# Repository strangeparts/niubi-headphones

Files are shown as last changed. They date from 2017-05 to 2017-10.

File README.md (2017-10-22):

# niubi-headphones
Flexible circuit board design for adding a headphone jack to an iPhone 7

The design of this project is free for everyone. You have my full permission to make modification and improvement however you like.

Here is a picture of the board on the bottom flex cable.

I have used the internal circuit board from an official Apple headphone adapter.  The circuit connects this board to the lightning jack on the bottom flex connector.  When something is plugged into the lightning jack, the signal is switched from the headphone adapter to the lightning jack.  There is a 1 megaohm resistor that pulls the shield of the lightning connector to 3v.  This is shorted to ground when a connector is plugged into the headphone jack. This is how the switching chip senses that something was plugged in.  Whenever something is plugged or unplugged, one of the two timers fires, temporarily disabling the switching chip for 100ms (I think), which appears to be necessary for the phone to sense that something has been plugged in.

There are a couple limitations of this design:
- You cannot use the headphone jack while anything is plugged into the lightning jack.
- You need to move taptic engine and battery upward and shave the headphone jack, case, and screen to get enough room for the flex pcb, headphone adapter board, and flex pcb to fit.

## Contribute

If you decide to improve or manufacture this - I would love to hear from you.  You can contact me here: https://strangeparts.com/contact.

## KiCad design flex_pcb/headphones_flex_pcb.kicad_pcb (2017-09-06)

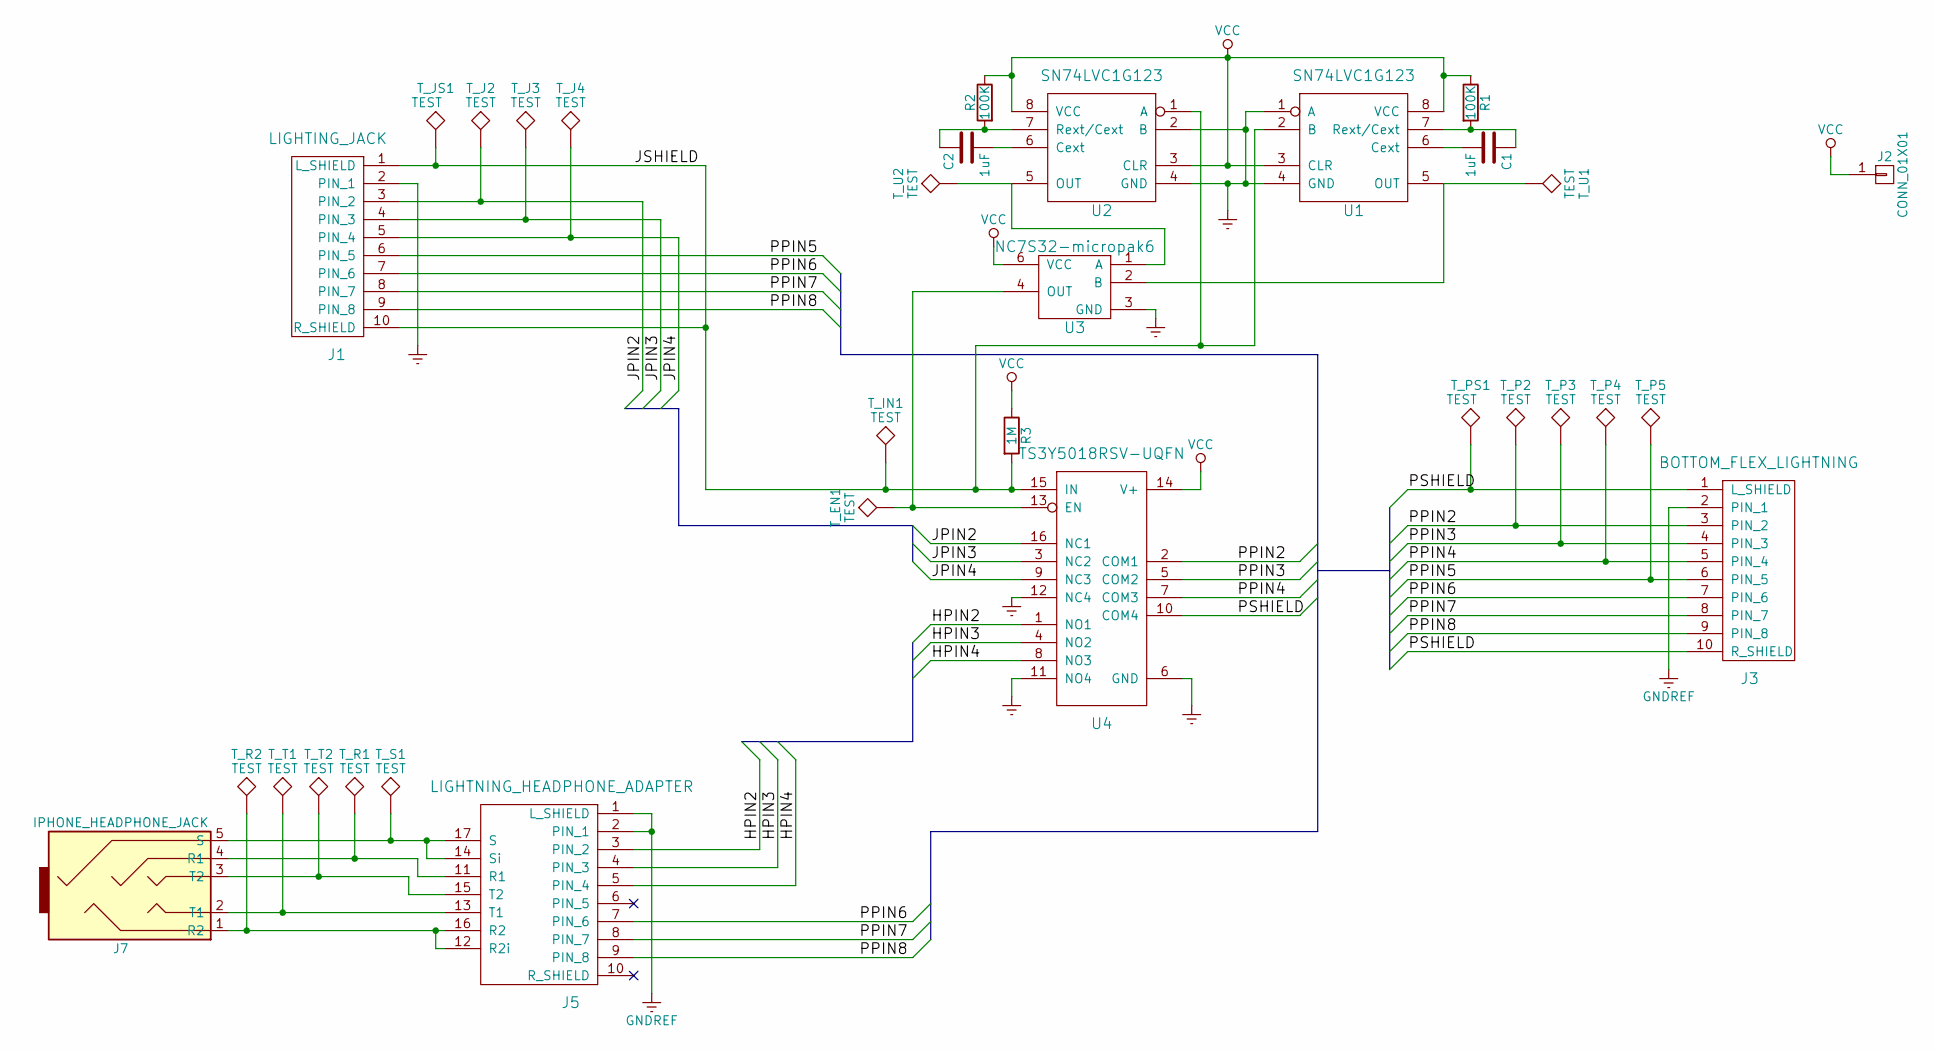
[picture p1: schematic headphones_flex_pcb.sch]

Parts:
C1, C2: 1uF; C_0402_NoSilk
J1: LIGHTING_JACK; LIGHTNING_JACK_NO_LEFT_HOLES
J2: CONN_01X01; WIRE_PAD_2x3mm
J3: BOTTOM_FLEX_LIGHTNING; LIGHTNING_FLEX_PADS_NO_CRTYD
J5: LIGHTNING_HEADPHONE_ADAPTER; LIGHTNING_HEADPHONE_ADAPTER_HANDWIRE
J7: IPHONE_HEADPHONE_JACK; IPHONE_5_HEADPHONE_JACK
R1, R2: 100K; R_0402_NoSilk
R3: 1M; R_0402_NoSilk
T_EN1: TEST; testpoint_1mm
T_IN1: TEST; testpoint_1mm
T_J2, T_J3, T_J4: TEST; testpoint_1mm
T_JS1: TEST; testpoint_1mm
T_P2, T_P3, T_P4, T_P5: TEST; testpoint_1mm
T_PS1: TEST; testpoint_1mm
T_R1, T_R2: TEST; testpoint_1mm
T_S1: TEST; testpoint_1mm
T_T1, T_T2: TEST; testpoint_1mm
T_U1, T_U2: TEST; testpoint_1mm
U1, U2: SN74LVC1G123; DSBGA-8_2x4_0.9x1.9mm_Pitch0.5mm_Dia0.25mm
U3: NC7S32-micropak6; Micropak6
U4: TS3Y5018RSV-UQFN; R-PUQFN-N16

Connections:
/HPIN2: J5.3 (PIN_2), U4.1 (NO1)
/HPIN3: J5.4 (PIN_3), U4.4 (NO2)
/HPIN4: J5.5 (PIN_4), U4.8 (NO3)
/JPIN2: J1.3 (PIN_2), T_J2.1, U4.16 (NC1)
/JPIN3: J1.4 (PIN_3), T_J3.1, U4.3 (NC2)
/JPIN4: J1.5 (PIN_4), T_J4.1, U4.9 (NC3)
/JSHIELD: J1.1 (L_SHIELD), J1.10 (R_SHIELD), R3.2, T_IN1.1, T_JS1.1, U1.2 (B), U2.1 (A), U4.15 (IN)
/PPIN2: J3.3 (PIN_2), T_P2.1, U4.2 (COM1)
/PPIN3: J3.4 (PIN_3), T_P3.1, U4.5 (COM2)
/PPIN4: J3.5 (PIN_4), T_P4.1, U4.7 (COM3)
/PPIN5: J1.6 (PIN_5), J3.6 (PIN_5), T_P5.1
/PPIN6: J1.7 (PIN_6), J3.7 (PIN_6), J5.7 (PIN_6)
/PPIN7: J1.8 (PIN_7), J3.8 (PIN_7), J5.8 (PIN_7)
/PPIN8: J1.9 (PIN_8), J3.9 (PIN_8), J5.9 (PIN_8)
/PSHIELD: J3.1 (L_SHIELD), J3.10 (R_SHIELD), T_PS1.1, U4.10 (COM4)
GNDREF: J1.2 (PIN_1), J3.2 (PIN_1), J5.1 (L_SHIELD), J5.2 (PIN_1), U1.1 (A), U1.4 (GND), U2.2 (B), U2.4 (GND), U3.3 (GND), U4.6 (GND), U4.11 (NO4), U4.12 (NC4)
unnamed: C1.1, R1.2, U1.7 (Rext/Cext)
unnamed: C1.2, U1.6 (Cext)
unnamed: C2.1, R2.2, U2.7 (Rext/Cext)
unnamed: C2.2, U2.6 (Cext)
unnamed: J5.11 (R1), J7.4 (R1), T_R1.1
unnamed: J5.12 (R2i), J5.16 (R2), J7.1 (R2), T_R2.1
unnamed: J5.13 (T1), J7.2 (T1), T_T1.1
unnamed: J5.14 (Si), J5.17 (S), J7.5 (S), T_S1.1
unnamed: J5.15 (T2), J7.3 (T2), T_T2.1
unnamed: T_EN1.1, U3.4 (OUT), U4.13 (EN)
unnamed: T_U1.1, U1.5 (OUT), U3.2 (B)
unnamed: T_U2.1, U2.5 (OUT), U3.1 (A)
VCC: J2.1, R1.1, R2.1, R3.1, U1.3 (CLR), U1.8 (VCC), U2.3 (CLR), U2.8 (VCC), U3.6 (VCC), U4.14 (V+)

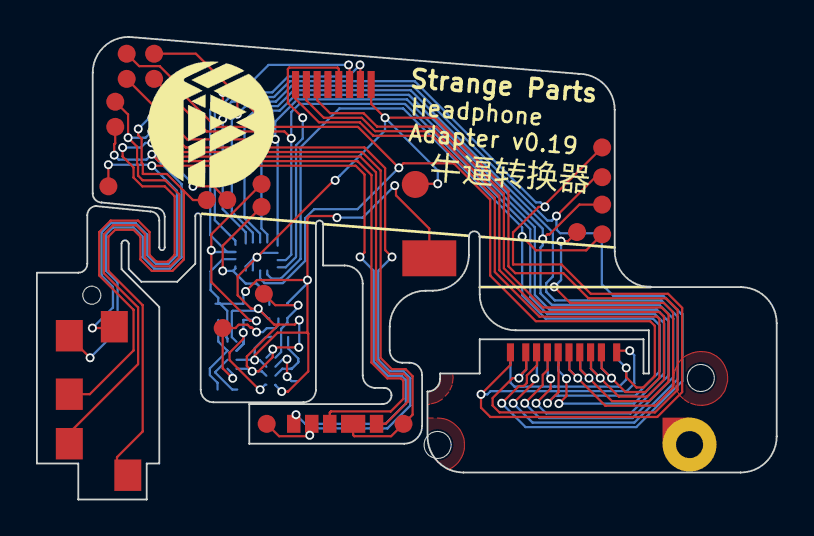
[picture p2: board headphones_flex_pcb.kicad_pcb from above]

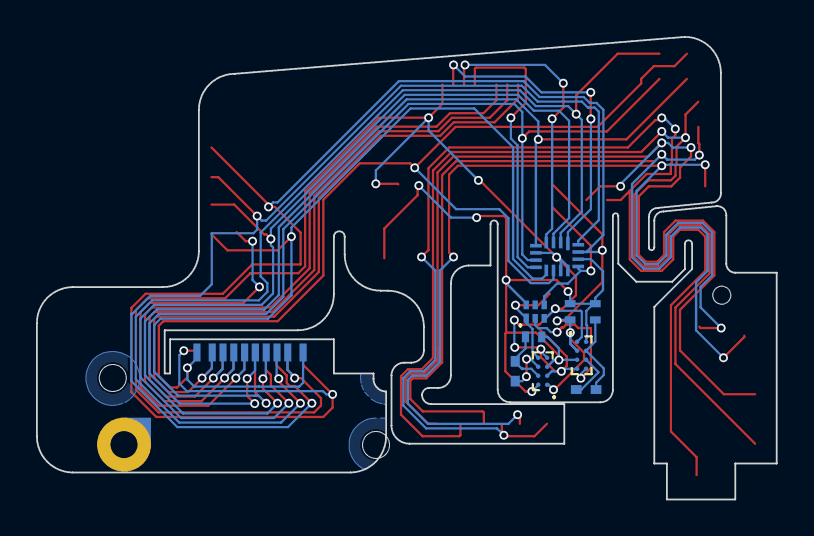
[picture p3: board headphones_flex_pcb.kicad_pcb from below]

Board: 2 copper layers, 41.1 x 25.7 mm, 32 parts (10 on the bottom side), 29 nets.

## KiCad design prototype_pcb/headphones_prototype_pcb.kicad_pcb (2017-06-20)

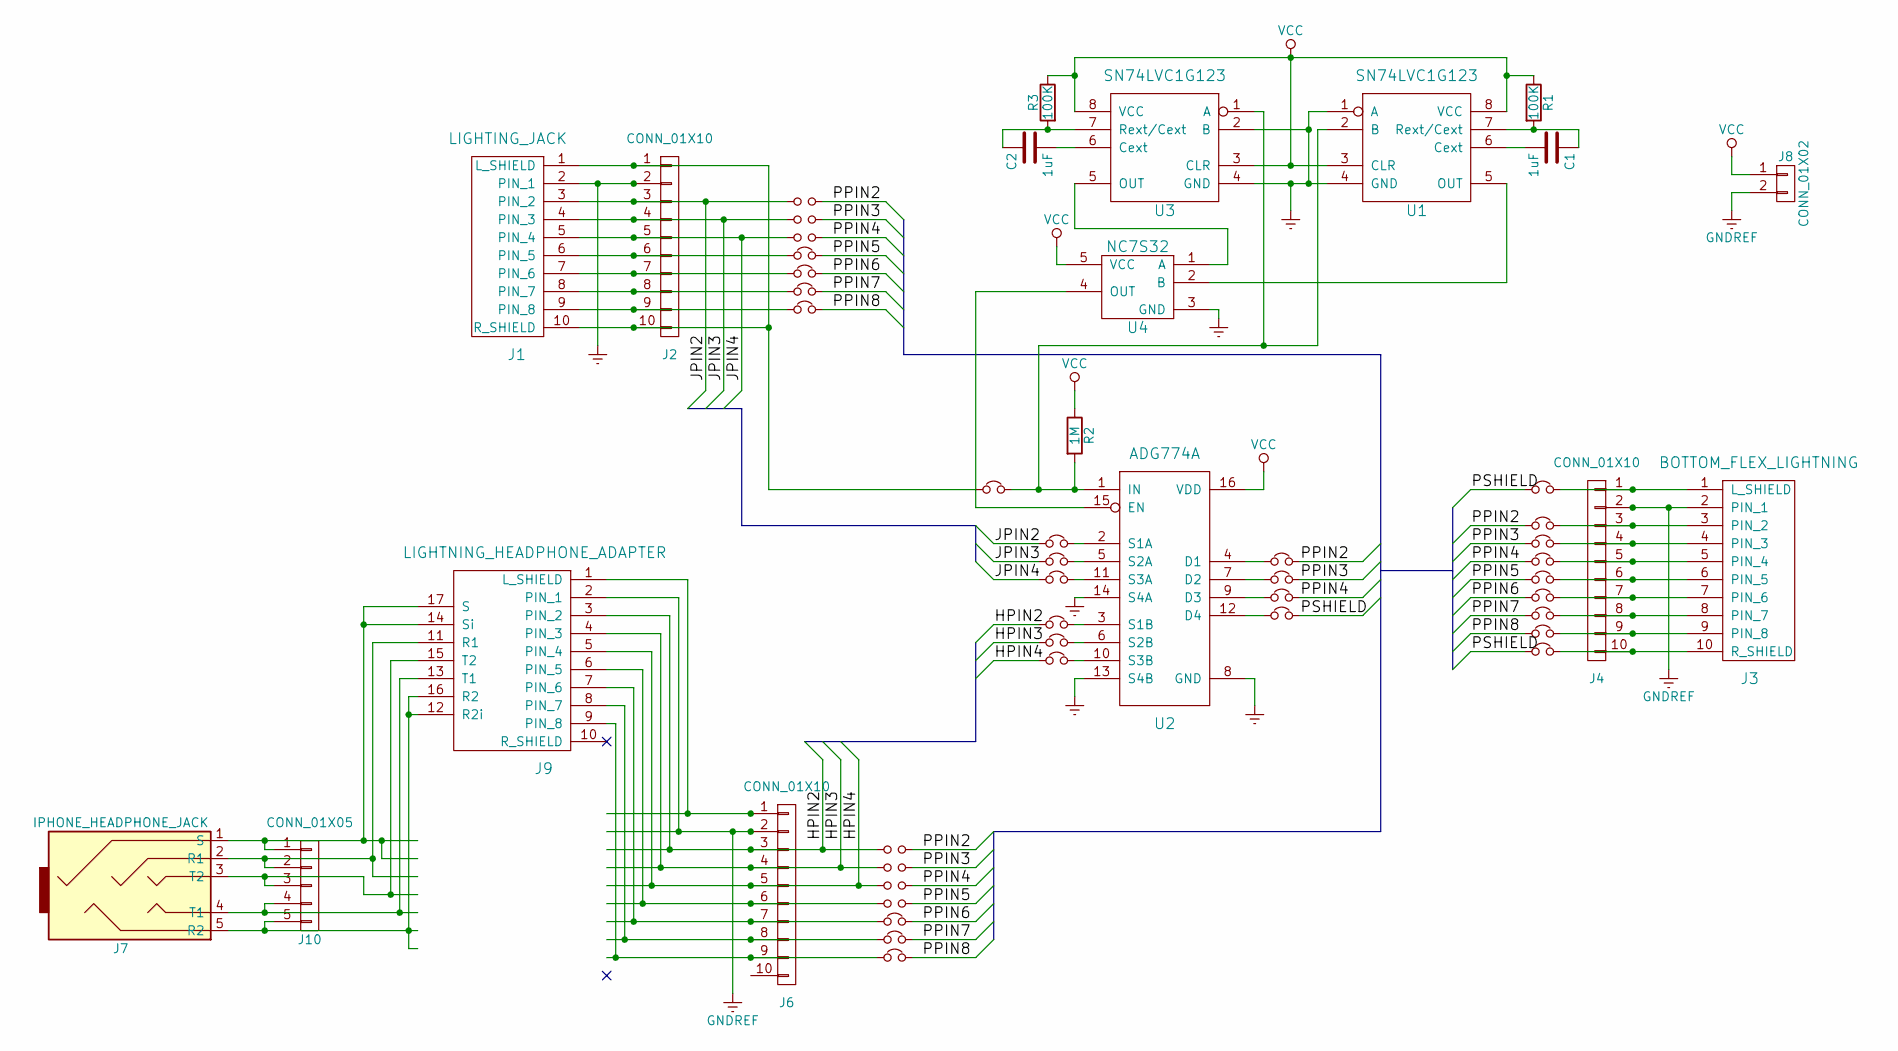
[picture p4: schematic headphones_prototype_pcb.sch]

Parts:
C1, C2: 1uF; C_0805_HandSoldering
J1: LIGHTING_JACK; LIGHTNING_JACK
J2, J4, J6: CONN_01X10; Pin_Header_Straight_1x10_Pitch2.54mm
J3: BOTTOM_FLEX_LIGHTNING; LIGHTNING_FLEX_PADS
J7: IPHONE_HEADPHONE_JACK; IPHONE_6S_HEADPHONE_JACK
J8: CONN_01X02; Pin_Header_Straight_1x02_Pitch2.54mm
J9: LIGHTNING_HEADPHONE_ADAPTER; LIGHTNING_HEADPHONE_ADAPTER_HANDWIRE
J10: CONN_01X05; Pin_Header_Straight_1x05_Pitch2.54mm
JP1, JP2, JP3, JP28, JP29, JP30, JP31: Jumper_NO_Small; PAD-JUMPER-2-NO_NO_SILK
JP4, JP5, JP6, JP7, JP8, JP9, JP10, JP11, JP12, JP13, JP14, JP15, JP16, JP17, JP18, JP19, JP20, JP21, JP22, JP23, JP24, JP25, JP26, JP27, JP32, JP33, JP34: Jumper_NC_Small; PAD-JUMPER-2-NC_BY_TRACE_NO_SILK
R1, R3: 100K; R_0805_HandSoldering
R2: 1M; R_0805_HandSoldering
U1, U3: SN74LVC1G123; SSOP-8_2.95x2.8mm_Pitch0.65mm
U2: ADG774A; QSOP-16_3.9x4.9mm_Pitch0.635mm
U4: NC7S32; SOT23-5

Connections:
/HPIN2: J6.3, J9.3 (PIN_2), JP23.1, JP28.1
/HPIN3: J6.4, J9.4 (PIN_3), JP25.1, JP29.1
/HPIN4: J6.5, J9.5 (PIN_4), JP27.1, JP30.1
/JPIN2: J1.3 (PIN_2), J2.3, JP1.1, JP11.1
/JPIN3: J1.4 (PIN_3), J2.4, JP2.1, JP13.1
/JPIN4: J1.5 (PIN_4), J2.5, JP3.1, JP16.1
/PPIN2: JP1.2, JP10.2, JP14.2, JP28.2
/PPIN3: JP2.2, JP12.2, JP17.2, JP29.2
/PPIN4: JP3.2, JP15.2, JP19.2, JP30.2
/PPIN5: JP4.2, JP18.2, JP31.2
/PPIN6: JP5.2, JP20.2, JP32.2
/PPIN7: JP6.2, JP22.2, JP33.2
/PPIN8: JP7.2, JP24.2, JP34.2
/PSHIELD: JP9.2, JP21.2, JP26.2
GNDREF: J1.2 (PIN_1), J2.2, J3.2 (PIN_1), J4.2, J6.2, J8.2, J9.2 (PIN_1), U1.1 (A), U1.4 (GND), U2.8 (GND), U2.13 (S4B), U2.14 (S4A), U3.2 (B), U3.4 (GND), U4.3 (GND)
unnamed: C1.1, R1.2, U1.7 (Rext/Cext)
unnamed: C1.2, U1.6 (Cext)
unnamed: C2.1, R3.2, U3.7 (Rext/Cext)
unnamed: C2.2, U3.6 (Cext)
unnamed: J1.1 (L_SHIELD), J1.10 (R_SHIELD), J2.1, J2.10, JP8.1
unnamed: J1.6 (PIN_5), J2.6, JP4.1
unnamed: J1.7 (PIN_6), J2.7, JP5.1
unnamed: J1.8 (PIN_7), J2.8, JP6.1
unnamed: J1.9 (PIN_8), J2.9, JP7.1
unnamed: J3.1 (L_SHIELD), J4.1, JP9.1
unnamed: J3.3 (PIN_2), J4.3, JP10.1
unnamed: J3.4 (PIN_3), J4.4, JP12.1
unnamed: J3.5 (PIN_4), J4.5, JP15.1
unnamed: J3.6 (PIN_5), J4.6, JP18.1
unnamed: J3.7 (PIN_6), J4.7, JP20.1
unnamed: J3.8 (PIN_7), J4.8, JP22.1
unnamed: J3.9 (PIN_8), J4.9, JP24.1
unnamed: J3.10 (R_SHIELD), J4.10, JP26.1
unnamed: J6.1, J9.1 (L_SHIELD)
unnamed: J6.6, J9.6 (PIN_5), JP31.1
unnamed: J6.7, J9.7 (PIN_6), JP32.1
unnamed: J6.8, J9.8 (PIN_7), JP33.1
unnamed: J6.9, J9.9 (PIN_8), JP34.1
unnamed: J7.1 (S), J9.14 (Si), J9.17 (S), J10.1
unnamed: J7.2 (R1), J9.11 (R1), J10.2
unnamed: J7.3 (T2), J9.15 (T2), J10.3
unnamed: J7.4 (T1), J9.13 (T1), J10.4
unnamed: J7.5 (R2), J9.12 (R2i), J9.16 (R2), J10.5
unnamed: JP8.2, R2.2, U1.2 (B), U2.1 (IN), U3.1 (A)
unnamed: JP11.2, U2.2 (S1A)
unnamed: JP13.2, U2.5 (S2A)
unnamed: JP14.1, U2.4 (D1)
unnamed: JP16.2, U2.11 (S3A)
unnamed: JP17.1, U2.7 (D2)
unnamed: JP19.1, U2.9 (D3)
unnamed: JP21.1, U2.12 (D4)
unnamed: JP23.2, U2.3 (S1B)
unnamed: JP25.2, U2.6 (S2B)
unnamed: JP27.2, U2.10 (S3B)
unnamed: U1.5 (OUT), U4.2 (B)
unnamed: U2.15 (EN), U4.4 (OUT)
unnamed: U3.5 (OUT), U4.1 (A)
VCC: J8.1, R1.1, R2.1, R3.1, U1.3 (CLR), U1.8 (VCC), U2.16 (VDD), U3.3 (CLR), U3.8 (VCC), U4.5 (VCC)

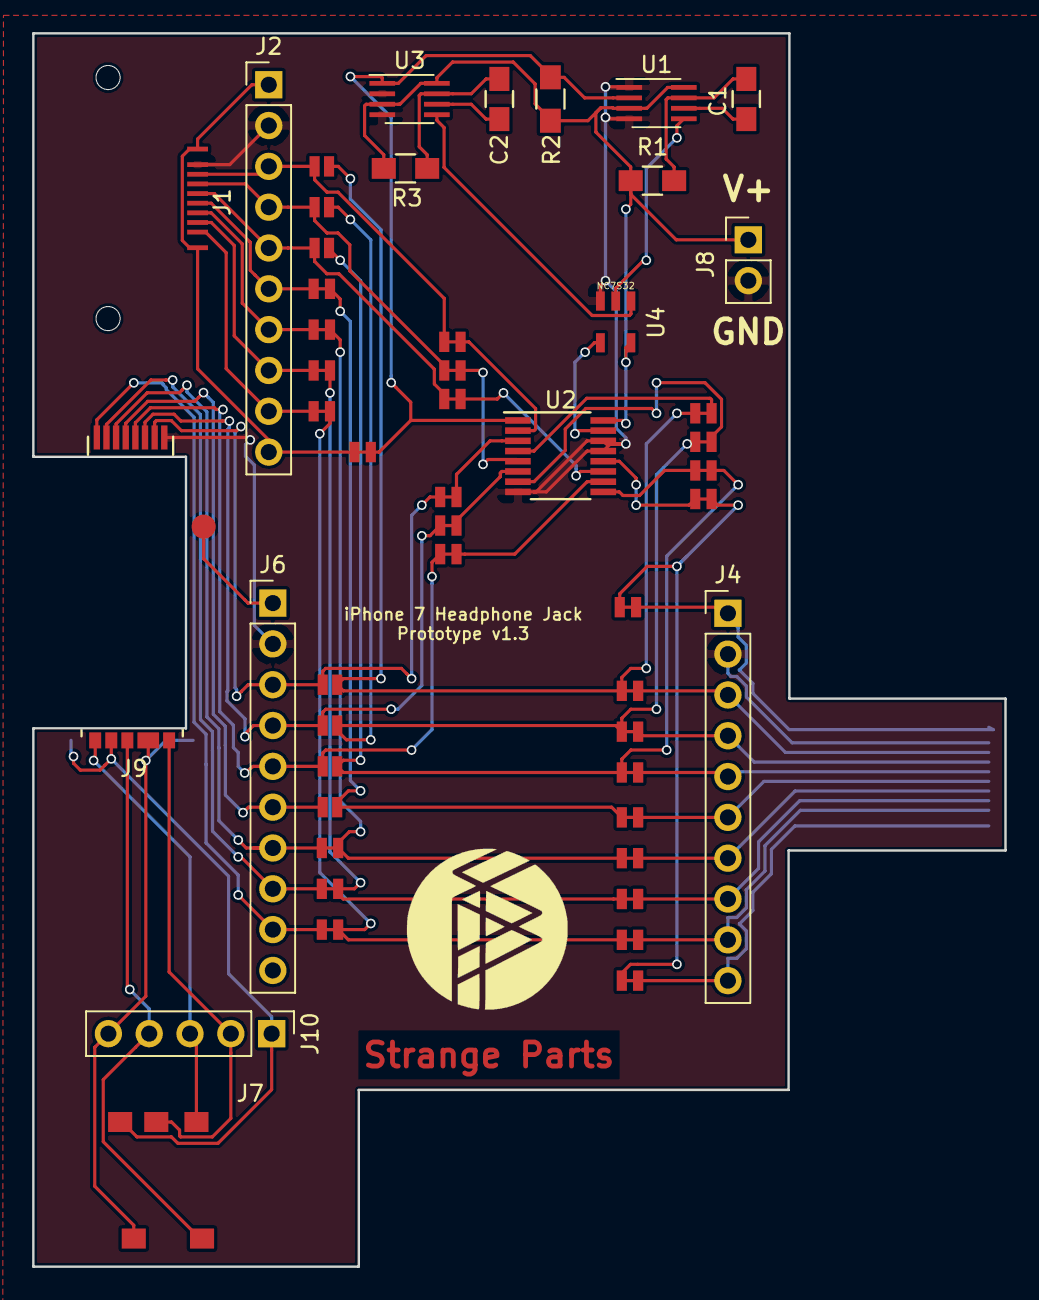
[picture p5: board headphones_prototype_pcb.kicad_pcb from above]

Board: 2 copper layers, 60.5 x 76.8 mm, 52 parts (1 on the bottom side), 58 nets.

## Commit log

2017-05-21 initial version
    [ADG774A_breakout.kicad_pcb, ADG774A_breakout.sch, headphones.kicad_pcb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]
2017-05-21 Move 1st attempt to v1/
    [ADG774A_breakout.kicad_pcb, ADG774A_breakout.sch, headphones.kicad_pcb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]
2017-05-26 Prototype board v1
    [headphones_prototype_pcb.dsn, headphones_prototype_pcb.kicad_pcb, headphones_prototype_pcb.sch]
2017-06-09 Rigid prototype pcb v1.2
    [headphones_prototype_pcb.kicad_pcb, headphones_prototype_pcb.sch]
2017-06-09 Flex PCB - first version
    first printed paper prototype, with some trial routing.
    [headphones_flex_pcb.dsn, headphones_flex_pcb.kicad_pcb, headphones_flex_pcb.sch]
2017-06-12 About to try front fold
    [headphones_flex_pcb.kicad_pcb, headphones_flex_pcb.sch]
2017-06-13 WIP: just before switching from 0201 -> 0402
    [headphones_flex_pcb.kicad_pcb, headphones_flex_pcb.sch]
2017-06-13 First flex pcb version - ready to fab. v0.9
    [headphones_flex_pcb.kicad_pcb, headphones_flex_pcb.sch]
2017-06-19 Switch to using iphone 5 headphone jack
    [headphones_flex_pcb.kicad_pcb]
2017-06-20 Switch headphone adapter to handwired
    [headphones_flex_pcb.kicad_pcb, headphones_flex_pcb.sch]
2017-06-20 Remove castellated edges adapter from prototype
    [headphones_prototype_pcb.kicad_pcb, headphones_prototype_pcb.sch]
2017-06-20 Tweaks suggested by Lisa for manufacturability
    - Change vias from 0.3/0.4 to 0.3/0.5
    - Move tracks around lightning connector to at least 0.15mm away from board edge.
    - Add silkscreen for all edge cuts (since they won’t cut for me)
    [headphones_flex_pcb.kicad_pcb]
2017-06-20 Tweaks to hopefully get rid of the large circles.
    This seems to be only a problem on Lisa’s software.
    Also add the holes for the lightning connector as actual drill holes in hopes they will drill them for me.
    [headphones_flex_pcb.kicad_pcb]
2017-06-20 Move all the components to the bottom side
    This is on Lisa’s recommendation. She says because the FPC is so thin, it will be hard to solder if they’re on both sides.
    [headphones_flex_pcb.kicad_pcb]
2017-07-09 v0.17
    I redesigned the flex pcb to use the TS3A5018 chip
    for switching instead of the ADG774A. This supports
    a 3v signal, whereas the ADG774A only supported up
    to 1.5v. Also a bunch of minor tweaks to the board
    design to make it easier to assemble and test (added
    test pads!)
    Also made a rigid version of the flex pcb, to help
    debug manufacturing defects if necessary.
    [headphones_flex_pcb-rigid.kicad_pcb, headphones_flex_pcb.sch]
2017-07-10 Remove slots that are too small from rigid flex pcb
    HQPCB says they can only do min 0.8mm slots.
    [headphones_flex_pcb-rigid.kicad_pcb]
2017-07-10 Make sure headphone jack holes have no solder mask
    Just trying to minimize confusion with the factory.
    [headphones_flex_pcb.kicad_pcb]
2017-07-10 Made tab with lighting pads slightly longer.
    [headphones_flex_pcb.kicad_pcb]
2017-07-24 Tweaks after v0.17
    -Remove copper pours on IC area
    -Fix misnumbered pads on micropak6
    [headphones_flex_pcb.kicad_pcb]
2017-07-24 Zigzag attempt 1
    [headphones_flex_pcb.kicad_pcb]
2017-07-24 Tweak edges and silkscreens
    [headphones_flex_pcb.kicad_pcb]
2017-07-24 v0.18
    - Tweak tracks into headphone jack to make them narrower.
    [headphones_flex_pcb.kicad_pcb]
